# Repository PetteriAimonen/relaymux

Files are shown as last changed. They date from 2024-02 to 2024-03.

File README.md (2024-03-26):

# USB Relay Mux box

This repository contains hardware and firmware for a USB Relay Mux that has two independent halves,
each of which multiplexes a pair of signals to four channels. It is designed for use in automatic
testing, for example to switch input signals to multimeter or to change polarity of a power supply.

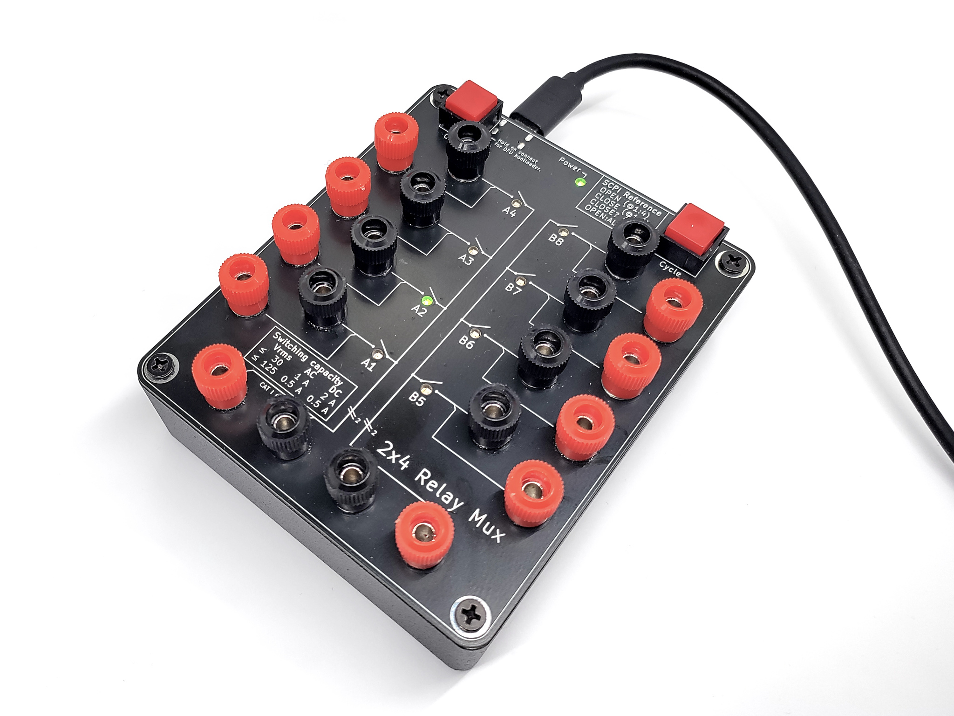
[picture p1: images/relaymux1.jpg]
[](images/relaymux1.jpg)
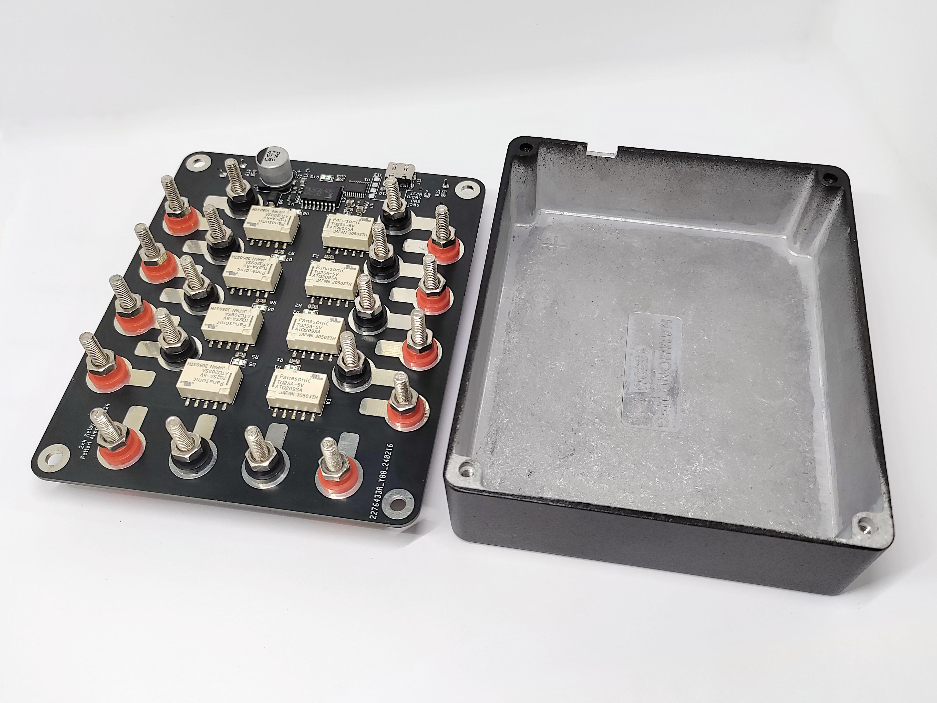
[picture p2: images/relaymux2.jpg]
[](images/relaymux2.jpg)

[**Schematic**](pcb/images/relaymux.pdf) - [**BOM**](pcb/gerbers/bom-generic.csv) - [**Gerbers**](pcb/gerbers/)

## Design

Many of the cheap USB relay boards are designed for switching large currents, and not for lab usage.
They have several shortcomings:

* Poor quality relays, which have varying amount of resistance when switching small currents.
* Weird custom protocol with no feedback from device.
* Excessive current draw from USB bus when all relays are activated.

This project implements the standard SCPI command set and uses higher quality [Panasonic TQ2SA-5V](https://na.industrial.panasonic.com/products/relays-contactors/mechanical-signal-relays/lineup/signal-relays/series/119572/model/119942) relays.

## Specifications

* Switching time: 10 ms
* Maximum current and voltage:
  * up to 30 Vrms: AC 1 A or DC 2 A
  * up to 125 Vrms: AC or DC 0.5 A
* Parasitic capacitance: 40 pF each signal to GND
* Wetting current: 10 µA
* Contact resistance: 50 mohm typical, max 150 mohm
* Power supply: USB 5V 300mA
* Control: SCPI over USB CDC-ACM serial port

## SCPI command set

* `*IDN?`: Query model name and serial number
* `OPEN @(1,2,5:8)`: Open (disconnect) one or multiple relay channels
* `CLOSE @(1,5)`: Close (connect) one or multiple relay channels
* `CLOSE? (@1)`: Query whether a specific channel is closed
* `CLOSE:STATE?`: Return a list of all closed channels
* `OPEN:ALL`: Open all channels
* `SET 255`: Set channel states as 8-bit integer, break-before-make
* `SET:MBB 255`: Set channel states as 8-bit integer, make-before-break
* `GET?`: Get channel states as 8-bit integer

The commands follow "Signal Switchers" instrument category of SCPI 1999 standard.

All commands wait for relay switching, so consecutive instructions will follow correct make/break sequencing.

## Parts

| Part | Info | Approx. cost (without taxes) |
|---|---|---|
| PCB | 120x100 mm, [gerbers](pcb/gerbers) | 8 EUR |
| Components | [Listed in BOM](pcb/gerbers/bom-generic.csv) | 18 EUR |
| Binding posts | 20 pcs, 5 mm mounting hole | 10 EUR |
| Enclosure | Hammond [1550MBK](https://www.hammfg.com/part/1550MBK) | 15 EUR |
| **Total** | | **51 EUR**|

The PCB is designed for mounting the binding posts directly with a nut to the 5 mm hole.
How well this works depends on the specific connector model.
If needed, the hole can be drilled larger without damage to the traces, and a soldering
area is provided in case there is no electrical contact through the screw.
Some solder is a good idea in any case to prevent it from the connector spinning in the hole.
Cheapest binding posts can be found on eBay, but some of them lack a hole for a wire.

The PCB replaces the original lid of the enclosure. A small notch needs to be filed for the USB-C connector to fit through.

## Firmware

STM32F042 firmware is based on STM32Cube USB-CDC library and [scpi-parser](https://github.com/j123b567/scpi-parser) library.

It can be built using [PlatformIO](https://platformio.org):

    pio run
    ...
    RAM:   [=====     ]  52.5% (used 3224 bytes from 6144 bytes)
    Flash: [========  ]  80.3% (used 26300 bytes from 32768 bytes)

The board can be programmed through USB DFU protocol using STM32 built-in bootloader.
The bootloader is activated by holding down `Clear` button while plugging in the cable.

## License

The electronics design is licensed under [CC-BY-4.0](https://creativecommons.org/licenses/by/4.0/deed.fi).
Suggested attribution format for derivative designs:

    Based on USB Relay Mux by Petteri Aimonen, https://github.com/PetteriAimonen/relaymux/

The firmware is licensed under [BSD 2-Clause license](LICENSE).

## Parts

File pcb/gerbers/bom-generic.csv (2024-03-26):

Reference | Value | Footprint | LCSC | MPN | Qty
C1, C3, C4 | 10µF | Capacitor_SMD:C_0805_2012Metric | C15850 | CL21A106KAYNNNE | 3
C5 | 470µF | Capacitor_SMD:CP_Elec_10x10 | C251022 | UWD1E471MCL1GS | 1
D1-D8, D10 | LED | relaymux:LED_LTST-C230 | C125106 | LTST-C230KGKT | 9
D9 | SMAJ5.0A | Diode_SMD:D_SMA | C2925443 | SMAJ5.0A | 1
H1-H4 | M3.5 | MountingHole:MountingHole_4mm_Pad |  |  | 4
J1 | A | relaymux:Binding_Post_Pair |  |  | 1
J2 | A1 | relaymux:Binding_Post_Pair_120deg |  |  | 1
J3 | A2 | relaymux:Binding_Post_Pair_120deg |  |  | 1
J4 | A3 | relaymux:Binding_Post_Pair_120deg |  |  | 1
J5 | A4 | relaymux:Binding_Post_Pair_120deg |  |  | 1
J6 | B | relaymux:Binding_Post_Pair |  |  | 1
J7 | B1 | relaymux:Binding_Post_Pair_60deg |  |  | 1
J8 | B2 | relaymux:Binding_Post_Pair_60deg |  |  | 1
J9 | B3 | relaymux:Binding_Post_Pair_60deg |  |  | 1
J10 | B4 | relaymux:Binding_Post_Pair_60deg |  |  | 1
J11 | USB_C | Connector_USB:USB_C_Receptacle_XKB_U262-16XN-4BVC11 | C319148 | USB4110 | 1
J12 | Debug | relaymux:Pads_1x04_P2.54mm_Vertical |  |  | 1
K1-K8 | TQ2SA-5V | relaymux:Relay_TQ2SA | C2858038 | TQ2SA-5V | 8
R1-R8, R13 | 470 | Resistor_SMD:R_0805_2012Metric | C17710 | Generic | 9
R9, R10 | 5k1 | Resistor_SMD:R_0805_2012Metric | C27834 | Generic | 2
R11, R12, R14, R15 | 68k | Resistor_SMD:R_0805_2012Metric | C17801 | Generic | 4
SW1 | Cycle | relaymux:SW_320E11 | C273375 | 320E11BLK | 1
SW2 | Boot/Clear | relaymux:SW_320E11 | C273375 | 320E11BLK | 1
U1 | STM32F042F6Px | Package_SO:TSSOP-20_4.4x6.5mm_P0.65mm | C2969989 | STM32F042F6P6 | 1
U2 | TBD62783A | Package_SO:SOP-18_7x12.5mm_P1.27mm | C97745 | TBD62783AFG,EL | 1
U3 | TPS2552D | Package_TO_SOT_SMD:SOT-23-6 | C46506 | TPS2552DBVR | 1
U4 | TLV70033_SOT23-5 | Package_TO_SOT_SMD:SOT-23-5 | C11337 | TLV70033DDCR | 1

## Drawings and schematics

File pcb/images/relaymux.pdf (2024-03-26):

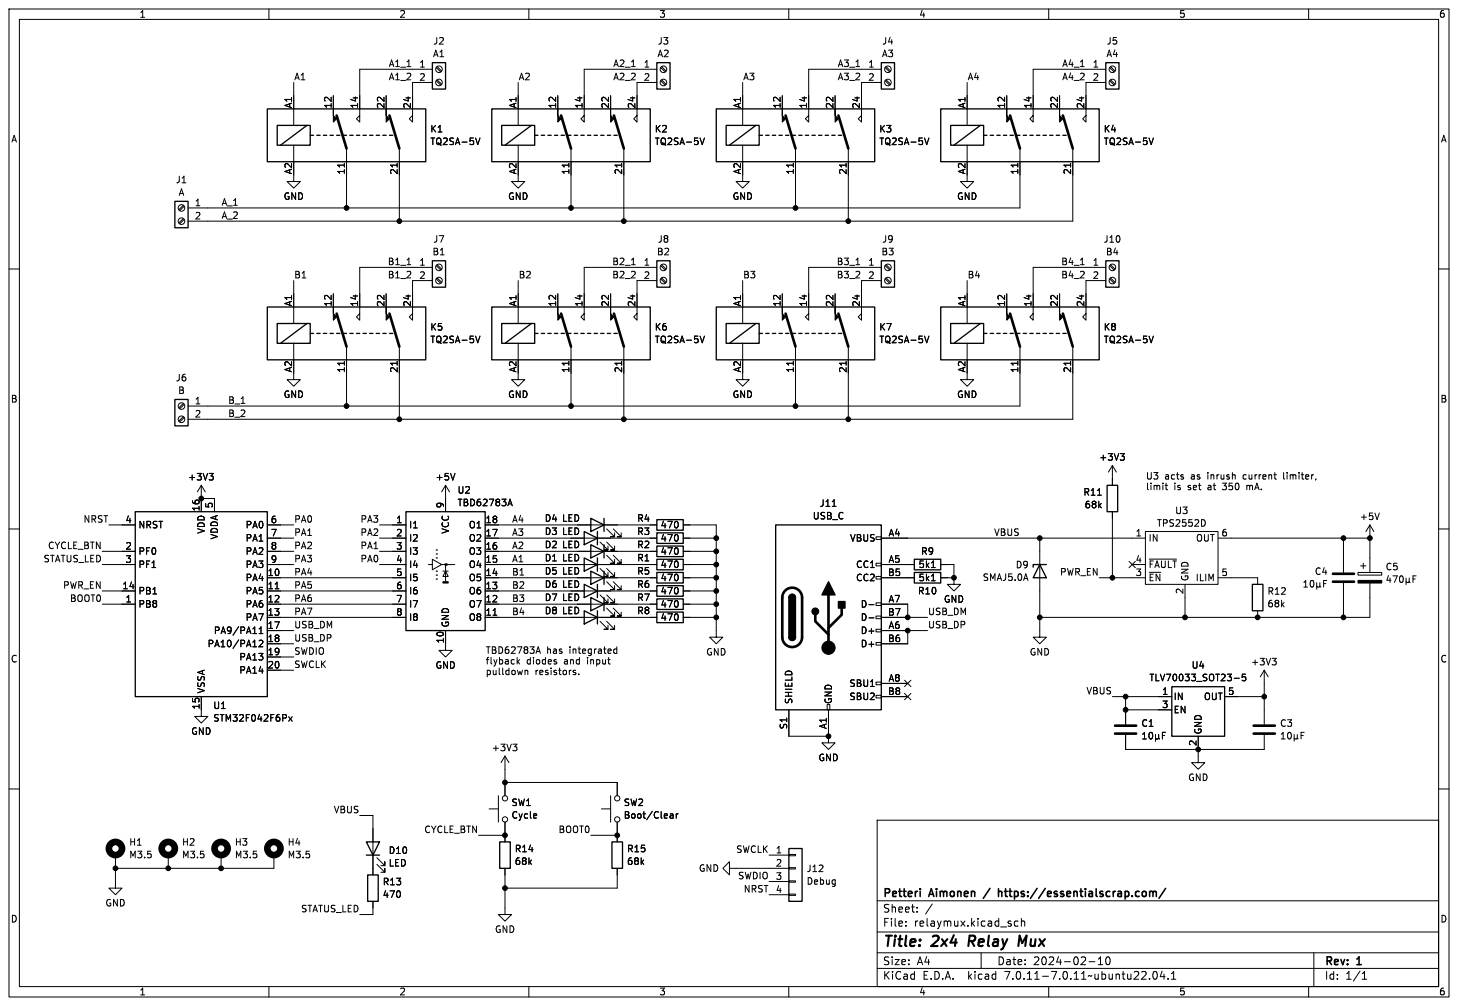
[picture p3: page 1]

limit is set at 350 mA. TBD62783A has integrated
U2 TBD62783A

flyback diodes and input

Id: 1/1 Title: 2x4 Relay Mux

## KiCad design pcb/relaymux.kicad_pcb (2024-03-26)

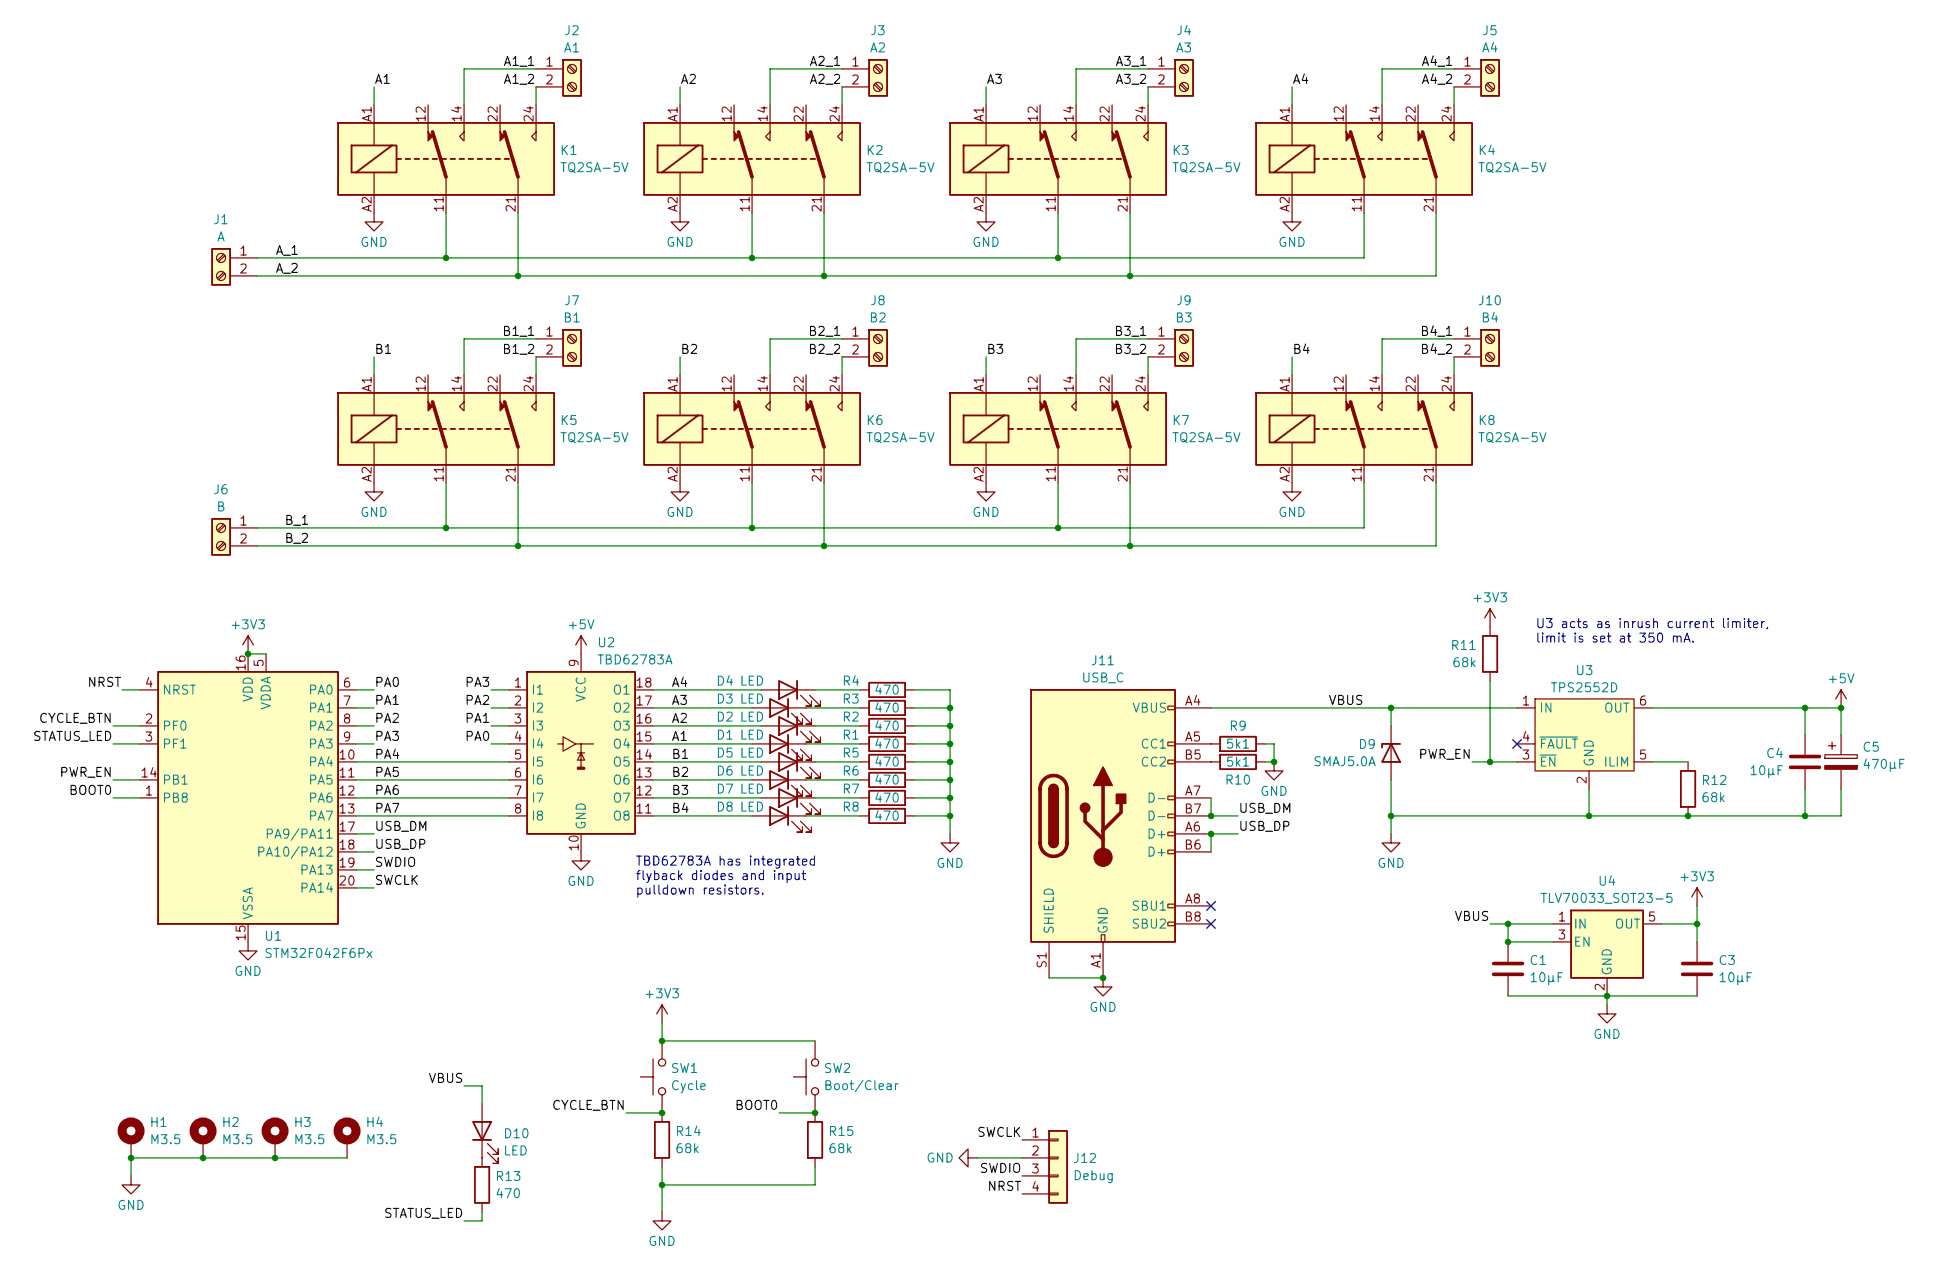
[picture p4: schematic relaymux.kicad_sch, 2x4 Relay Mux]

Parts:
C1, C3, C4: 10µF; C_0805_2012Metric; MPN CL21A106KAYNNNE; LCSC C15850
C5: 470µF; CP_Elec_10x10; MPN UWD1E471MCL1GS; LCSC C251022
D1, D2, D3, D4, D5, D6, D7, D8, D10: LED; LED_LTST-C230; MPN LTST-C230KGKT; LCSC C125106
D9: SMAJ5.0A; D_SMA; MPN SMAJ5.0A; LCSC C2925443
H1, H2, H3, H4: M3.5; MountingHole_4mm_Pad
J1: A; Binding_Post_Pair
J2: A1; Binding_Post_Pair_120deg
J3: A2; Binding_Post_Pair_120deg
J4: A3; Binding_Post_Pair_120deg
J5: A4; Binding_Post_Pair_120deg
J6: B; Binding_Post_Pair
J7: B1; Binding_Post_Pair_60deg
J8: B2; Binding_Post_Pair_60deg
J9: B3; Binding_Post_Pair_60deg
J10: B4; Binding_Post_Pair_60deg
J11: USB_C; USB_C_Receptacle_XKB_U262-16XN-4BVC11; MPN USB4110; LCSC C319148
J12: Debug; Pads_1x04_P2.54mm_Vertical
K1, K2, K3, K4, K5, K6, K7, K8: TQ2SA-5V; Relay_TQ2SA; MPN TQ2SA-5V; LCSC C2858038
R1, R2, R3, R4, R5, R6, R7, R8, R13: 470; R_0805_2012Metric; MPN Generic 470 ohm 0805; LCSC C17710
R9, R10: 5k1; R_0805_2012Metric; MPN Generic 5.1kohm 0805; LCSC C27834
R11, R12, R14, R15: 68k; R_0805_2012Metric; MPN Generic 68kohm 0805; LCSC C17801
SW1: Cycle; SW_320E11; MPN 320E11BLK; LCSC C273375
SW2: Boot/Clear; SW_320E11; MPN 320E11BLK; LCSC C273375
U1: STM32F042F6Px; TSSOP-20_4.4x6.5mm_P0.65mm; MPN STM32F042F6P6; LCSC C2969989
U2: TBD62783A; SOP-18_7x12.5mm_P1.27mm; MPN TBD62783AFG,EL; LCSC C97745
U3: TPS2552D; SOT-23-6; MPN TPS2552DBVR; LCSC C46506
U4: TLV70033_SOT23-5; SOT-23-5; MPN TLV70033DDCR; LCSC C11337

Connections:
+3V3: C3.1, R11.1, SW1.2, SW2.2, U1.5 (VDDA), U1.16 (VDD), U4.5 (OUT)
+5V: C4.1, C5.1, U2.9 (VCC), U3.6 (OUT)
/A1: D1.2 (A), K1.A1, U2.15 (O4)
/A1_1: J2.1, K1.14
/A1_2: J2.2, K1.24
/A2: D2.2 (A), K2.A1, U2.16 (O3)
/A2_1: J3.1, K2.14
/A2_2: J3.2, K2.24
/A3: D3.2 (A), K3.A1, U2.17 (O2)
/A3_1: J4.1, K3.14
/A3_2: J4.2, K3.24
/A4: D4.2 (A), K4.A1, U2.18 (O1)
/A4_1: J5.1, K4.14
/A4_2: J5.2, K4.24
/A_1: J1.1, K1.11, K2.11, K3.11, K4.11
/A_2: J1.2, K1.21, K2.21, K3.21, K4.21
/B1: D5.2 (A), K5.A1, U2.14 (O5)
/B1_1: J7.1, K5.14
/B1_2: J7.2, K5.24
/B2: D6.2 (A), K6.A1, U2.13 (O6)
/B2_1: J8.1, K6.14
/B2_2: J8.2, K6.24
/B3: D7.2 (A), K7.A1, U2.12 (O7)
/B3_1: J9.1, K7.14
/B3_2: J9.2, K7.24
/B4: D8.2 (A), K8.A1, U2.11 (O8)
/B4_1: J10.1, K8.14
/B4_2: J10.2, K8.24
/BOOT0: R15.1, SW2.1, U1.1 (PB8)
/B_1: J6.1, K5.11, K6.11, K7.11, K8.11
/B_2: J6.2, K5.21, K6.21, K7.21, K8.21
/CYCLE_BTN: R14.1, SW1.1, U1.2 (PF0)
/NRST: J12.4, U1.4 (NRST)
/PA0: U1.6 (PA0), U2.4 (I4)
/PA1: U1.7 (PA1), U2.3 (I3)
/PA2: U1.8 (PA2), U2.2 (I2)
/PA3: U1.9 (PA3), U2.1 (I1)
/PA4: U1.10 (PA4), U2.5 (I5)
/PA5: U1.11 (PA5), U2.6 (I6)
/PA6: U1.12 (PA6), U2.7 (I7)
/PA7: U1.13 (PA7), U2.8 (I8)
/PWR_EN: R11.2, U1.14 (PB1), U3.3 (~EN)
/STATUS_LED: R13.1, U1.3 (PF1)
/SWCLK: J12.1, U1.20 (PA14)
/SWDIO: J12.3, U1.19 (PA13)
/USB_DM: J11.A7 (D-), J11.B7 (D-), U1.17 (PA9/PA11)
/USB_DP: J11.A6 (D+), J11.B6 (D+), U1.18 (PA10/PA12)
/VBUS: C1.1, D9.1 (K), D10.2 (A), J11.A4 (VBUS), J11.A9 (VBUS), J11.B4 (VBUS), J11.B9 (VBUS), U3.1 (IN), U4.1 (IN), U4.3 (EN)
GND: C1.2, C3.2, C4.2, C5.2, D9.2 (A), H1.1, H2.1, H3.1, H4.1, J11.A1 (GND), J11.A12 (GND), J11.B1 (GND), J11.B12 (GND), J11.S1 (SHIELD), J12.2, K1.A2, K2.A2, K3.A2, K4.A2, K5.A2, K6.A2, K7.A2, K8.A2, R1.2, R2.2, R3.2, R4.2, R5.2, R6.2, R7.2, R8.2, R9.1, R10.1, R12.2, R14.2, R15.2, U1.15 (VSSA), U2.10 (GND), U3.2 (GND), U4.2 (GND)
unnamed: D1.1 (K), R1.1
unnamed: D2.1 (K), R2.1
unnamed: D3.1 (K), R3.1
unnamed: D4.1 (K), R4.1
unnamed: D5.1 (K), R5.1
unnamed: D6.1 (K), R6.1
unnamed: D7.1 (K), R7.1
unnamed: D8.1 (K), R8.1
unnamed: D10.1 (K), R13.2
unnamed: J11.A5 (CC1), R9.2
unnamed: J11.B5 (CC2), R10.2
unnamed: R12.1, U3.5 (ILIM)

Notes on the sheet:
U3 acts as inrush current limiter, limit is set at 350 mA.
TBD62783A has integrated flyback diodes and input pulldown resistors.

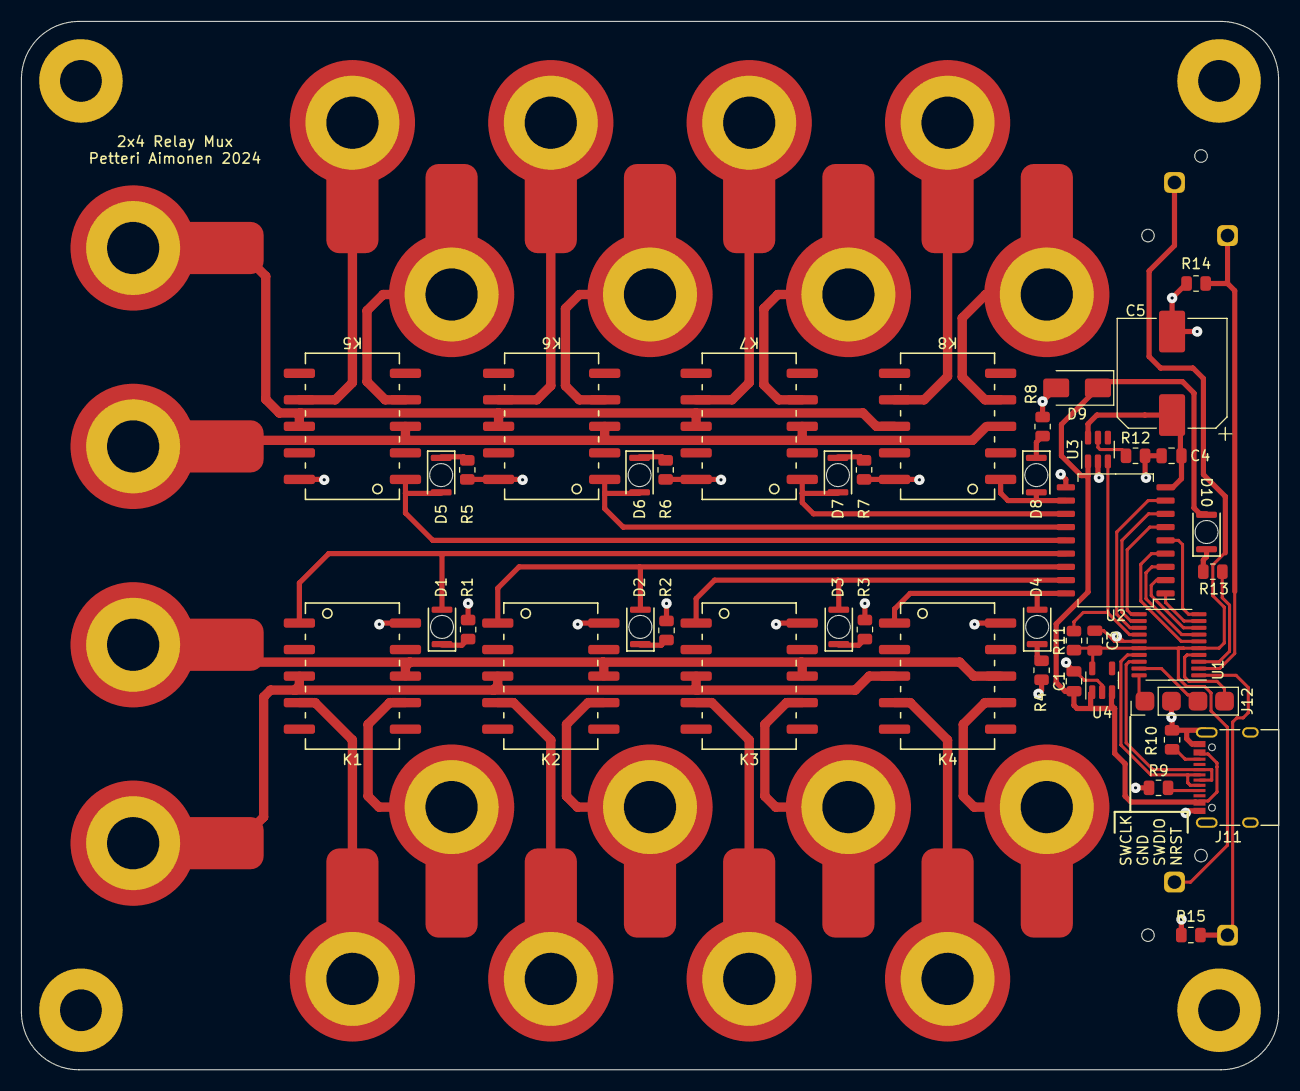
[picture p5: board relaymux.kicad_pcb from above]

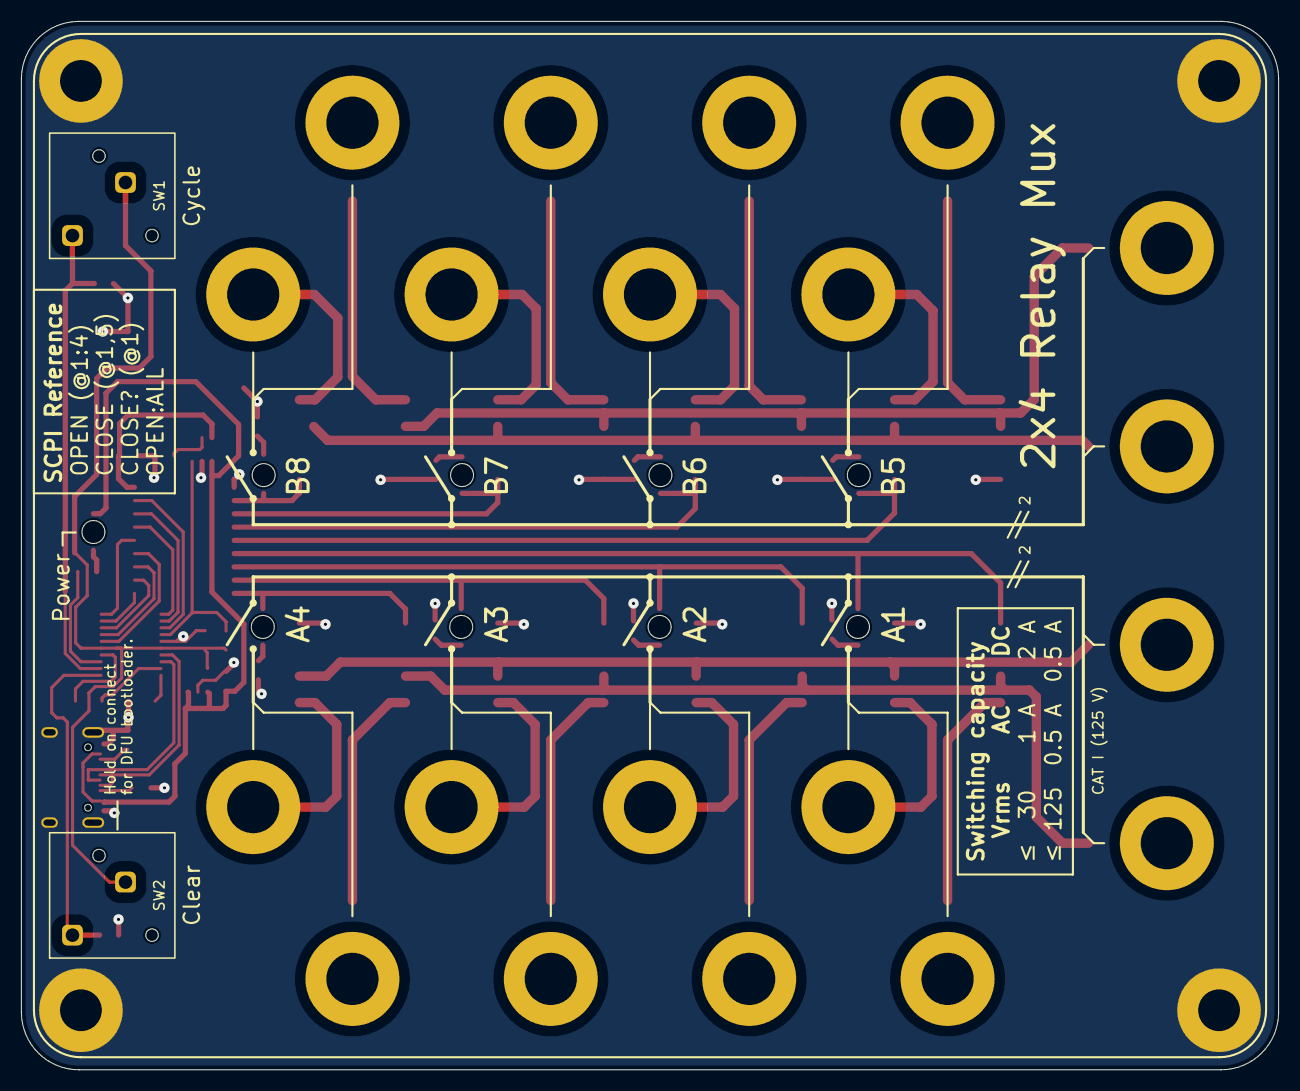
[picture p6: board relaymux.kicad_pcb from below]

Board: 2 copper layers, 120.4 x 100.4 mm, 59 parts (2 on the bottom side), 61 nets.

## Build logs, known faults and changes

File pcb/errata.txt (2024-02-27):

- Reverse led footprint, hole too large
- Switch footprint, misaligned NPTH

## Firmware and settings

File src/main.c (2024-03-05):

#include "board.h"
#include "usb_serial.h"
#include <stm32f0xx_hal.h>

void poll_buttons()
{
    uint32_t buttons = read_buttons();

    if (buttons & BTN_CLEAR)
    {
        // Open all relays
        open_relays(RELAY_MASK);
    }
    else if (buttons & BTN_CYCLE)
    {
        // Activate next relay in sequence
        uint32_t relays = relays_get_state();
        relays = (relays << 1) & RELAY_MASK;
        if (relays == 0)
            relays = 1;
        else if ((relays & (relays - 1)) != 0)
            relays = 1;

        open_relays(~relays);
        close_relays(relays);
    }
}

int main()
{
    board_init();
    STATUS_LED_ON();
    set_relay_pwr(true);

    usb_serial_start();

    while (1)
    {
        poll_buttons();
        usb_serial_poll();
    }
}

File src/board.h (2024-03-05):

// GPIO mapping for 2x4 relay mux board

#pragma once

#include <stm32f042x6.h>
#include <stm32f0xx_hal.h>
#include <stdbool.h>

#define CYCLE_BTN_PORT  GPIOF
#define CYCLE_BTN_PIN   GPIO_PIN_0

#define CLEAR_BTN_PORT  GPIOB
#define CLEAR_BTN_PIN   GPIO_PIN_8

#define BTN_DEBOUNCE_TIME_MS 100

#define STATUS_LED_PORT GPIOF
#define STATUS_LED_PIN  GPIO_PIN_1
#define STATUS_LED_ON() STATUS_LED_PORT->BRR = STATUS_LED_PIN
#define STATUS_LED_OFF() STATUS_LED_PORT->BSRR = STATUS_LED_PIN

#define PWR_EN_PORT     GPIOB
#define PWR_EN_PIN      GPIO_PIN_1

#define RELAY_PORT      GPIOA
#define RELAY_PIN_SHIFT 0
#define RELAY_COUNT     8
#define RELAY_MASK      0xFF
#define RELAY_OPERATE_DELAY_MS  10
#define RELAY_RELEASE_DELAY_MS  10

void board_init();

void set_relay_pwr(bool enable);
void close_relays(uint32_t channels);
void open_relays(uint32_t channels);
uint32_t relays_get_state();

#define BTN_CYCLE   0x01
#define BTN_CLEAR   0x02

// Returns button presses exactly once per press-and-release
uint32_t read_buttons();

// Simple logging to memory ringbuffer
void board_log(const char *data);

// Serial number for the device (from STM32 unique ID)
const char *board_serialnumber();

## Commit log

2024-02-15 First revision
    [bom.csv, relaymux.kicad_pcb, relaymux.kicad_sch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]
2024-02-27 Reorganize directories
    [bom.csv, relaymux.kicad_pcb, relaymux.kicad_sch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]
2024-03-05 First version of firmware
    [relaymux.kicad_pcb, relaymux.kicad_sch]
2024-03-05 Smaller holes for reverse mount LEDs
    [relaymux.kicad_pcb]
2024-03-26 Add readme, BOM
    [bom-generic.csv, bom-jlcpcb.csv, bom.csv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]
